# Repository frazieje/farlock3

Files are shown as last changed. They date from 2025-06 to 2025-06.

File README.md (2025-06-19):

Farlock3 is the 3rd generation of the FAR Door Lock. This version introduces several major changes over previous revisions.

This repository holds the KiCad schematic, PCB, BOM, and production files (gerber).

Features:

* New PCB design and layout
* nrf52840 SoC (MDBTQ50-U1MV2)
* Integrated h-bridge motor controller
* Integrated switch and LED electronics
* 64Mb external flash storage for Matter DFU
* USB micro B port for charging, shell access, etc
* ESD protection
* 3.3v voltage regulator
* Matter/ZephyrRTOS/OpenThread ready 

[farlock3 v02 schematic](farlock3.pdf)

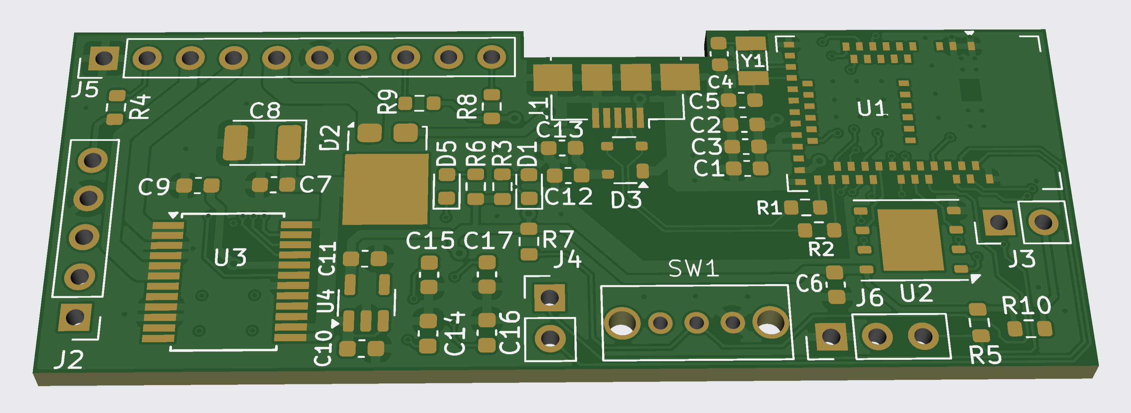
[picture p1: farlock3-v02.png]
farlock3 v02 PCB render


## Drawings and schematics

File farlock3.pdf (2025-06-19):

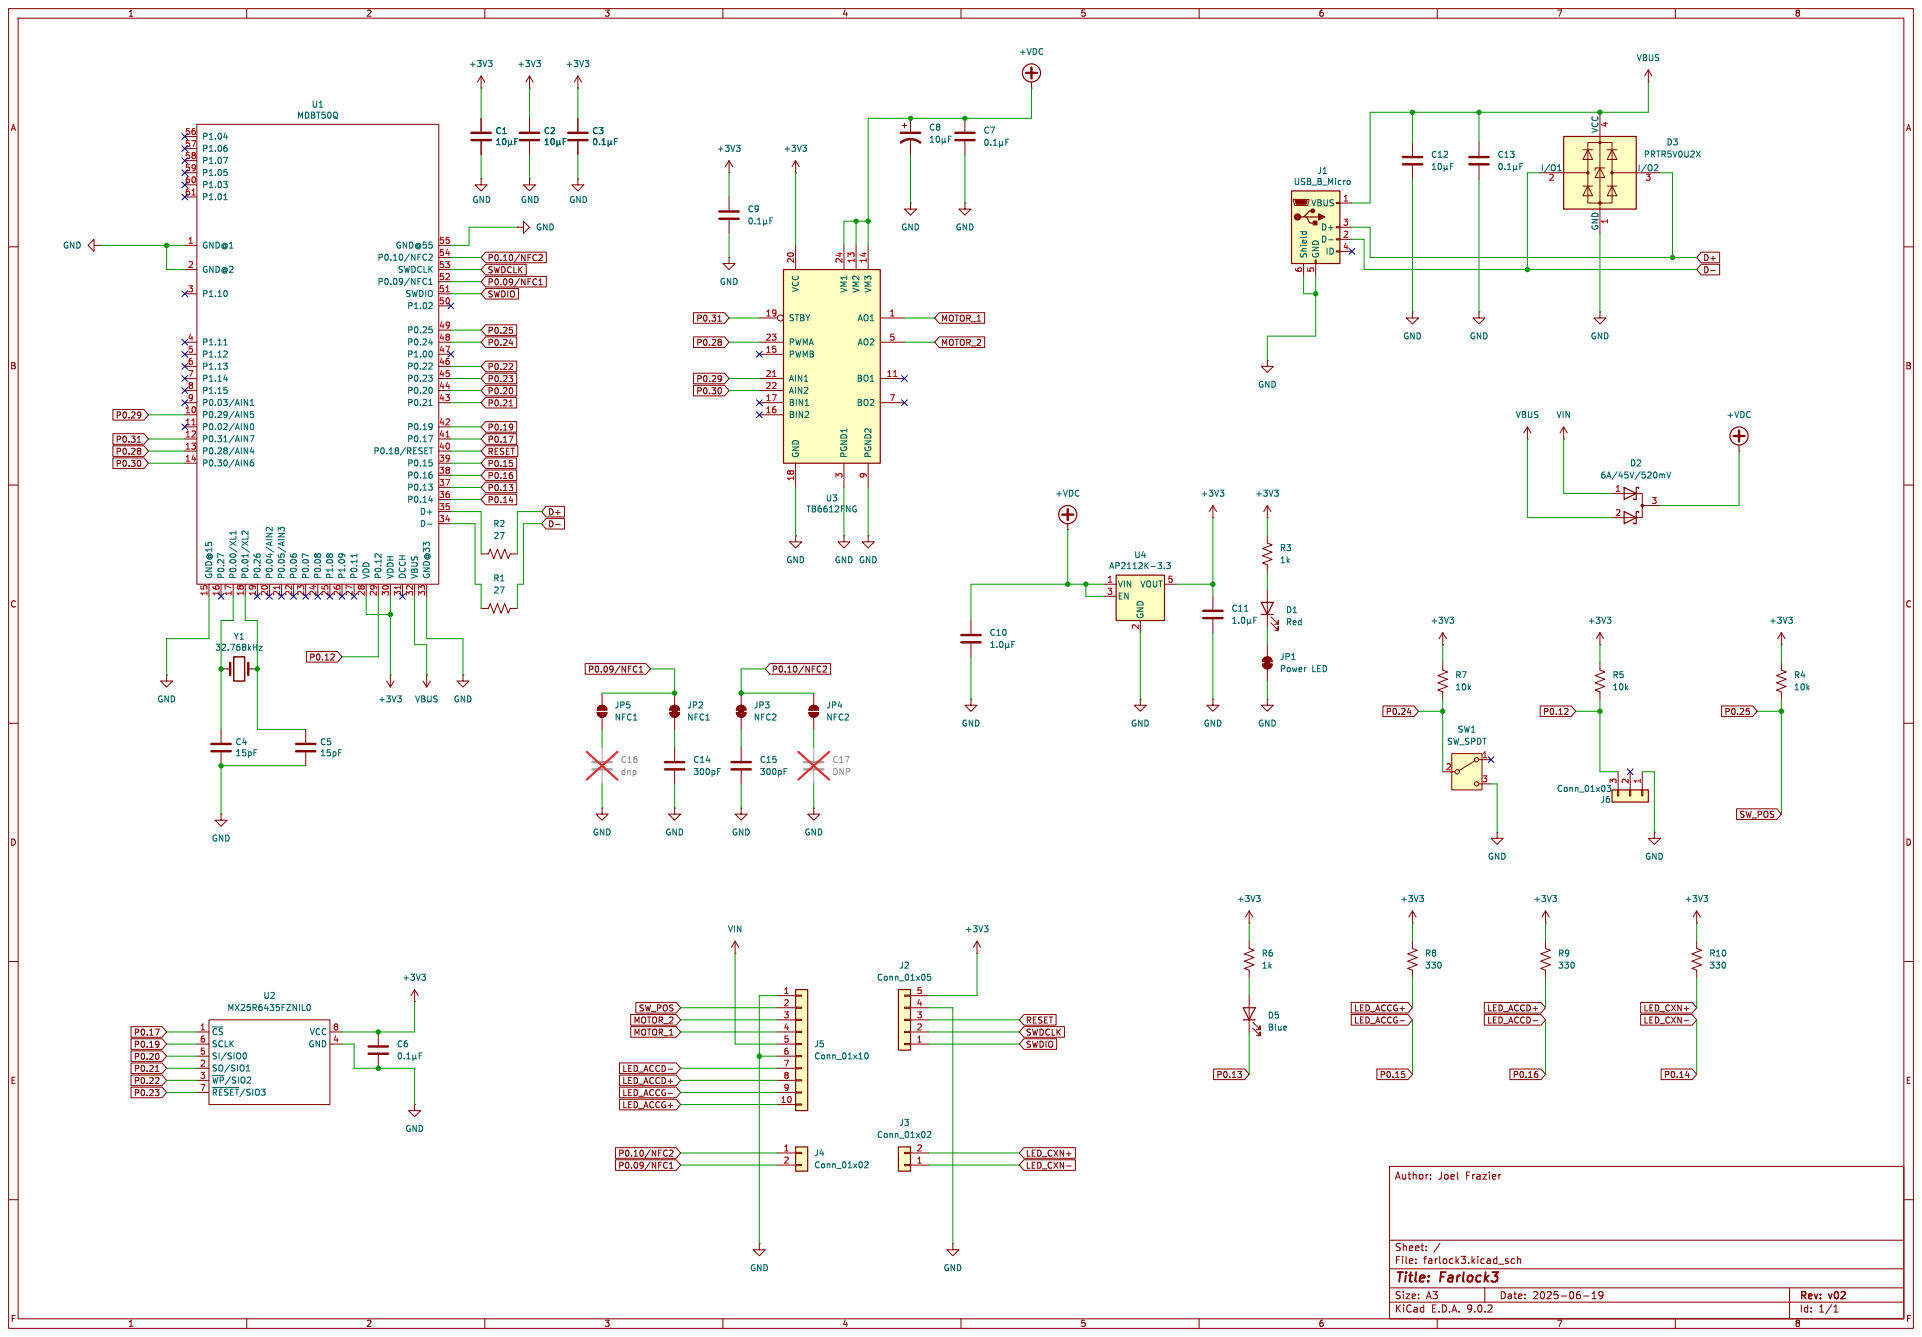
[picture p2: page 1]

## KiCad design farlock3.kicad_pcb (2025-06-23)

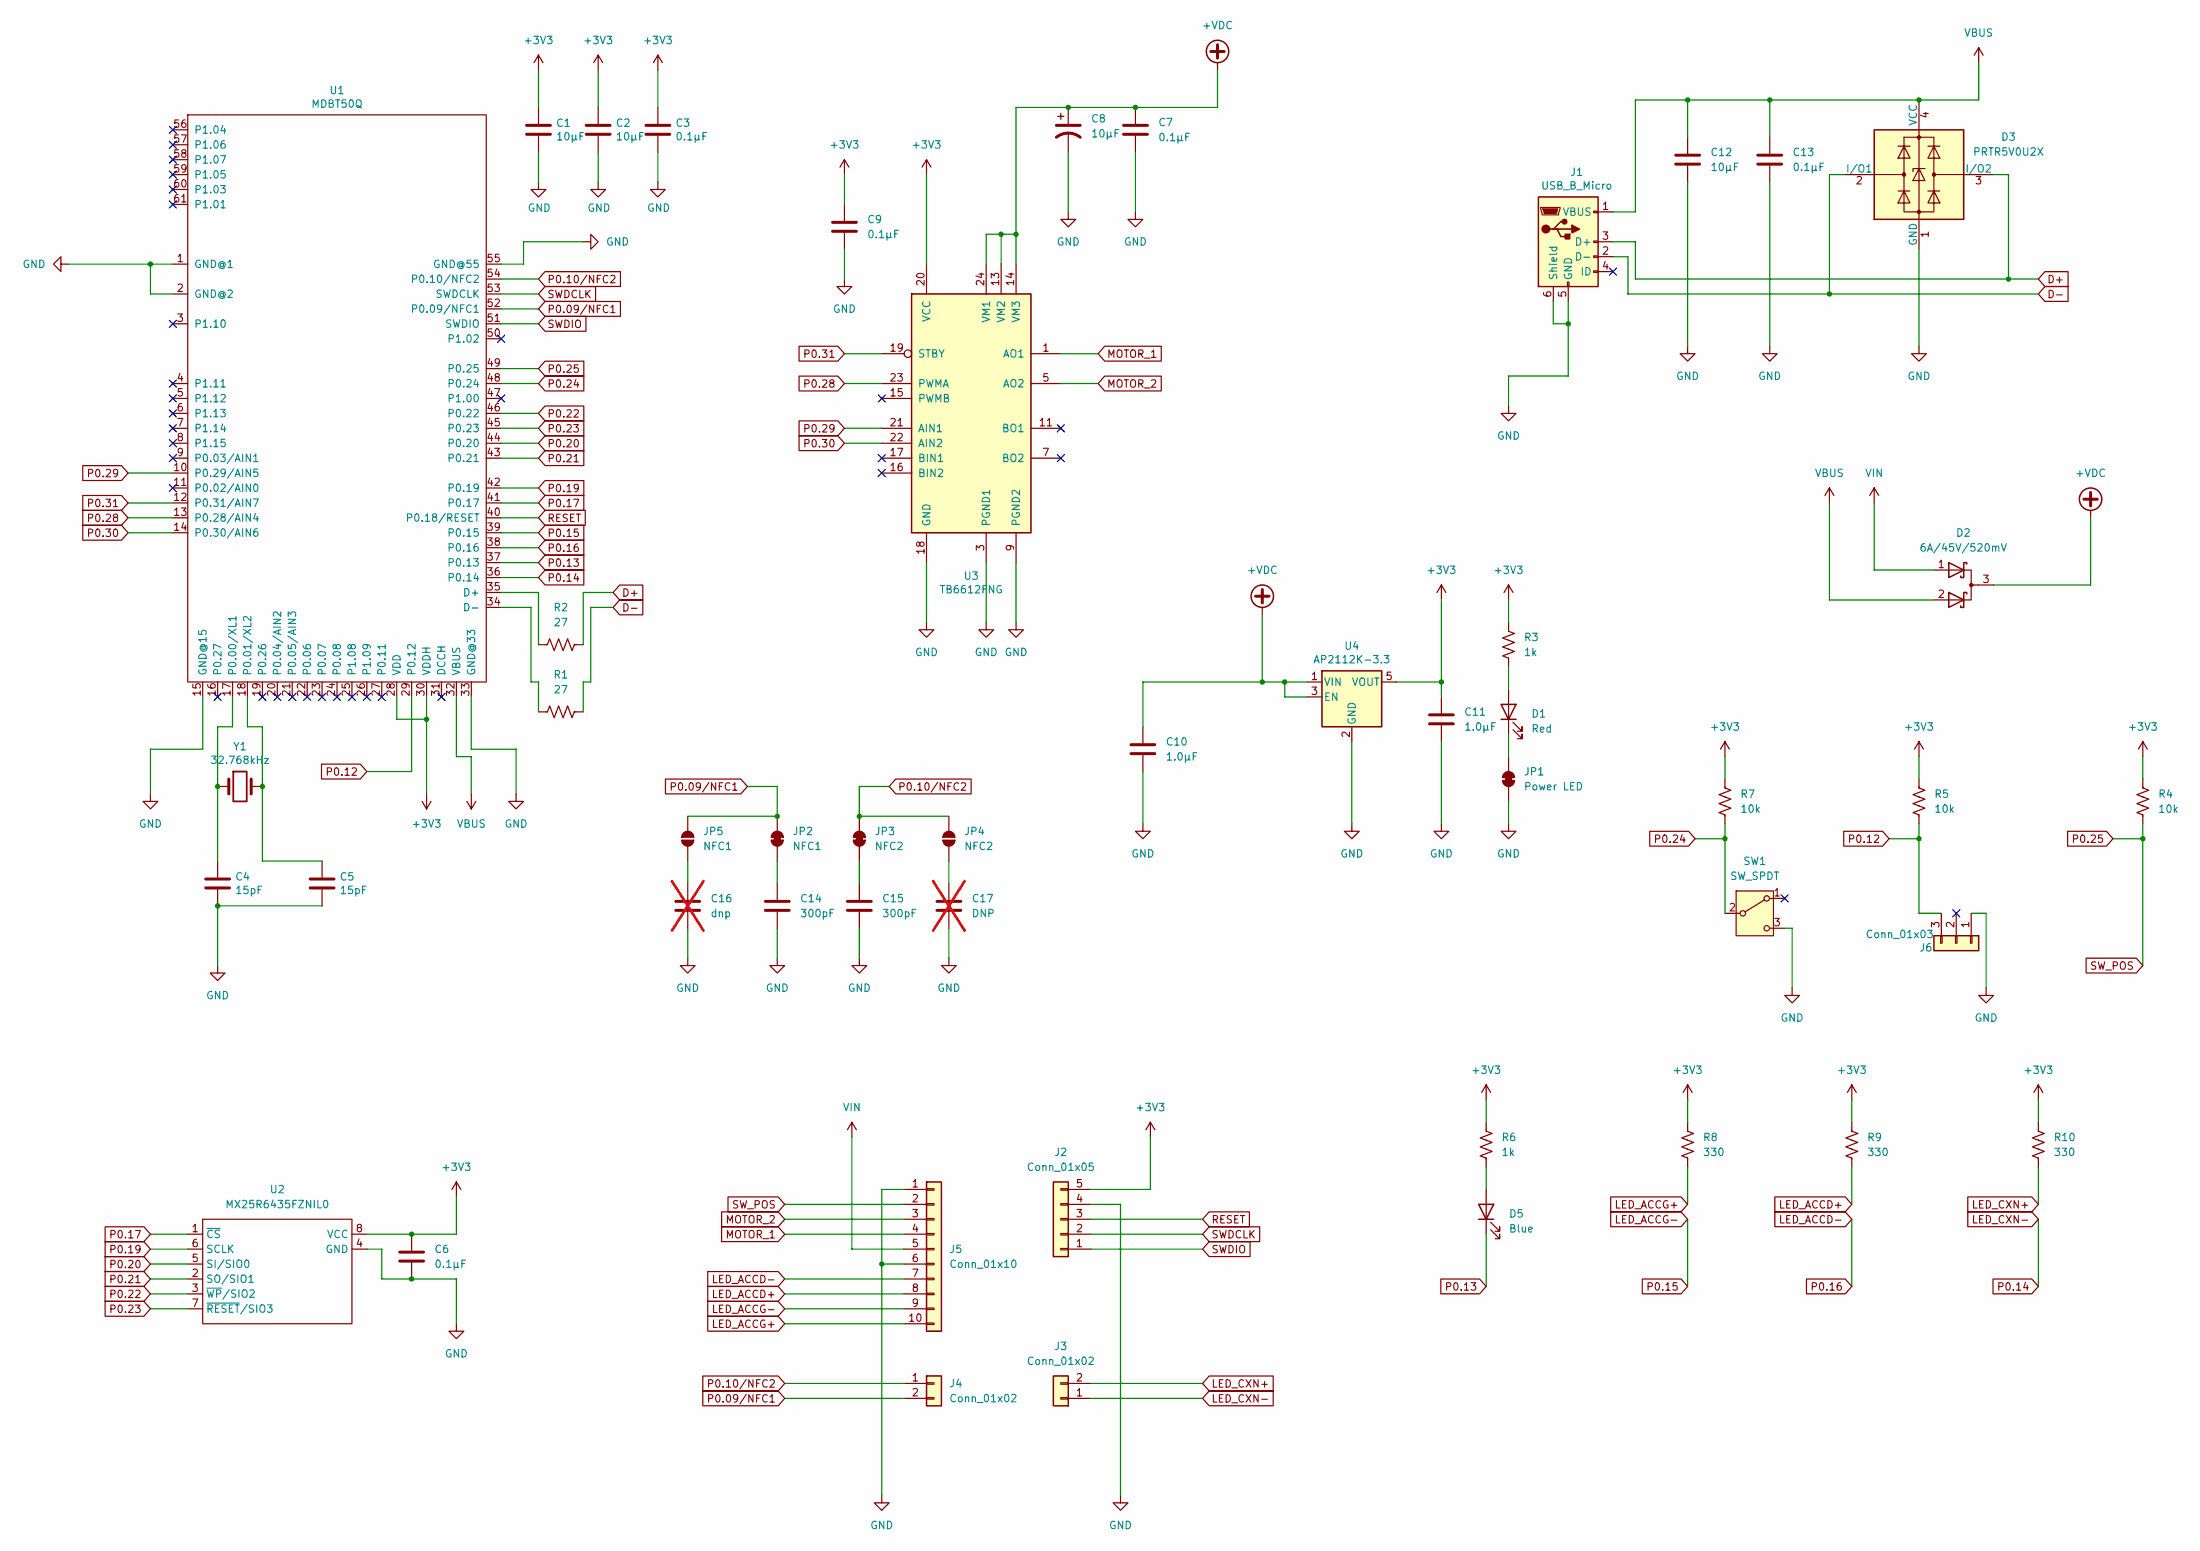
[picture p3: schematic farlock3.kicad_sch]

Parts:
C1, C2, C12: 10µF; C_0603_1608Metric; Manufacturer Part No CL10A106MP8NNNC
C3, C6, C7, C9, C13: 0.1µF; C_0603_1608Metric; Manufacturer Part No CL10B104KA8NNNC
C4, C5: 15pF; C_0603_1608Metric; Manufacturer Part No CL10C150JB8NNNC
C8: 10µF; CP_EIA-3528-21_Kemet-B; Manufacturer Part No 593D106X9020B2TE3
C10, C11: 1.0µF; C_0603_1608Metric; Manufacturer Part No CL10A105KO8NNNC
C14, C15: 300pF; C_0603_1608Metric; Manufacturer Part No C0603C301F5HACTU
C16: dnp; C_0603_1608Metric; not fitted
C17: DNP; C_0603_1608Metric; not fitted
D1: Red; LED_0603_1608Metric; Manufacturer Part No LTST-C190KRKT
D2: 6A/45V/520mV; TO-277A; Manufacturer Part No V10PL45-M3/86A
D3: PRTR5V0U2X; SOT-143; Manufacturer Part No PRTR5V0U2X
D5: Blue; LED_0603_1608Metric; Manufacturer Part No KB EELP41.12-P1R2-36-3X4X-5-R18
J1: USB_B_Micro; USB_Micro-B_Amphenol_10104110_Horizontal; Manufacturer Part No 10104110-0001LF
J2: Conn_01x05; PinHeader_1x05_P2.54mm_Vertical
J3, J4: Conn_01x02; PinHeader_1x02_P2.54mm_Vertical
J5: Conn_01x10; PinHeader_1x10_P2.54mm_Vertical
J6: Conn_01x03; PinHeader_1x03_P2.54mm_Vertical
JP1: Power LED; SolderJumper-2_P1.3mm_Bridged_RoundedPad1.0x1.5mm
JP2: NFC1; SolderJumper-2_P1.3mm_Bridged_RoundedPad1.0x1.5mm
JP3: NFC2; SolderJumper-2_P1.3mm_Bridged_RoundedPad1.0x1.5mm
JP4: NFC2; SolderJumper-2_P1.3mm_Open_RoundedPad1.0x1.5mm
JP5: NFC1; SolderJumper-2_P1.3mm_Open_RoundedPad1.0x1.5mm
R1, R2: 27; R_0603_1608Metric; Manufacturer Part No ERA-3AHD270V
R3, R6: 1k; R_0603_1608Metric; Manufacturer Part No ERA-3AEB102V
R4, R5, R7: 10k; R_0603_1608Metric; Manufacturer Part No ERJ-3GEYJ103V
R8, R9, R10: 330; R_0603_1608Metric; Manufacturer Part No ERA-3AEB331V
SW1: SW_SPDT; OS102011MA1QN1; Manufacturer Part No OS102011MA1QN1
U1: MDBT50Q; MDBT50Q-U1M; Manufacturer Part No MDBT50Q-U1MV2
U2: MX25R6435FZNIL0; WSON-8-1EP_6x5mm_P1.27mm_EP3.4x4mm; Manufacturer Part No MX25R6435FZNIL0
U3: TB6612FNG; SSOP-24_5.3x8.2mm_P0.65mm; Manufacturer Part No TB6612FNG,C,8,EL
U4: AP2112K-3.3; SOT-23-5; Manufacturer Part No AP2112K-3.3TRG1
Y1: 32.768kHz; Crystal_SMD_3215-2Pin_3.2x1.5mm; Manufacturer Part No CM7V-T1A-LOW-ESR-32.768KHZ-9PF-20-TA-QC

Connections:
+3V3: C1.1, C2.1, C3.1, C6.1, C9.1, C11.1, J2.5, R3.1, R4.2, R5.2, R6.1, R7.2, R8.1, R9.1, R10.1, U1.28 (VDD), U1.30 (VDDH), U2.8 (VCC), U3.20 (VCC), U4.5 (VOUT)
+VDC: C7.1, C8.1, C10.1, D2.3 (K), U3.13 (VM2), U3.14 (VM3), U3.24 (VM1), U4.1 (VIN), U4.3 (EN)
D+: D3.3 (I/O2), J1.3 (D+), R2.2
D-: D3.2 (I/O1), J1.2 (D-), R1.2
GND: C1.2, C2.2, C3.2, C4.2, C5.2, C6.2, C7.2, C8.2, C9.2, C10.2, C11.2, C12.2, C13.2, C14.2, C15.2, C16.2, C17.2, D3.1 (GND), J1.5 (GND), J1.6 (Shield), J2.4, J5.1, J5.6, J6.1, JP1.1 (A), SW1.3 (C), U1.1 (GND@1), U1.2 (GND@2), U1.15 (GND@15), U1.33 (GND@33), U1.55 (GND@55), U2.4 (GND), U3.3 (PGND1), U3.4 (PGND1), U3.9 (PGND2), U3.10 (PGND2), U3.18 (GND), U4.2 (GND)
LED_ACCD+: J5.8, R9.2
LED_ACCD-: J5.7, U1.38 (P0.16)
LED_ACCG+: J5.10, R8.2
LED_ACCG-: J5.9, U1.39 (P0.15)
LED_CXN+: J3.2, R10.2
LED_CXN-: J3.1, U1.36 (P0.14)
MOTOR_1: J5.4, U3.1 (AO1), U3.2 (AO1)
MOTOR_2: J5.3, U3.5 (AO2), U3.6 (AO2)
unnamed: D1.2 (A), R3.2
unnamed: D1.1 (K), JP1.2 (B)
unnamed: D5.2 (A), R6.2
unnamed: C14.1, JP2.1 (A)
unnamed: C15.1, JP3.1 (A)
unnamed: C17.1, JP4.1 (A)
unnamed: C16.1, JP5.1 (A)
unnamed: R2.1, U1.35 (D+)
unnamed: R1.1, U1.34 (D-)
unnamed: C4.1, U1.17 (P0.00/XL1), Y1.1
unnamed: C5.1, U1.18 (P0.01/XL2), Y1.2
P0.09/NFC1: J4.2, JP2.2 (B), JP5.2 (B), U1.52 (P0.09/NFC1)
P0.10/NFC2: J4.1, JP3.2 (B), JP4.2 (B), U1.54 (P0.10/NFC2)
P0.12: J6.3, R5.1, U1.29 (P0.12)
P0.13: D5.1 (K), U1.37 (P0.13)
P0.17: U1.41 (P0.17), U2.1 (~CS)
P0.19: U1.42 (P0.19), U2.6 (SCLK)
P0.20: U1.44 (P0.20), U2.5 (SI/SIO0)
P0.21: U1.43 (P0.21), U2.2 (SO/SIO1)
P0.22: U1.46 (P0.22), U2.3 (~WP/SIO2)
P0.23: U1.45 (P0.23), U2.7 (~RESET/SIO3)
P0.24: R7.1, SW1.2 (B), U1.48 (P0.24)
P0.25: J5.2, R4.1, U1.49 (P0.25)
P0.28: U1.13 (P0.28/AIN4), U3.23 (PWMA)
P0.29: U1.10 (P0.29/AIN5), U3.21 (AIN1)
P0.30: U1.14 (P0.30/AIN6), U3.22 (AIN2)
P0.31: U1.12 (P0.31/AIN7), U3.19 (STBY)
RESET: J2.3, U1.40 (P0.18/RESET)
SWDCLK: J2.2, U1.53 (SWDCLK)
SWDIO: J2.1, U1.51 (SWDIO)
VBUS: C12.1, C13.1, D2.2 (A), D3.4 (VCC), J1.1 (VBUS), U1.32 (VBUS)
VIN: D2.1 (A), J5.5

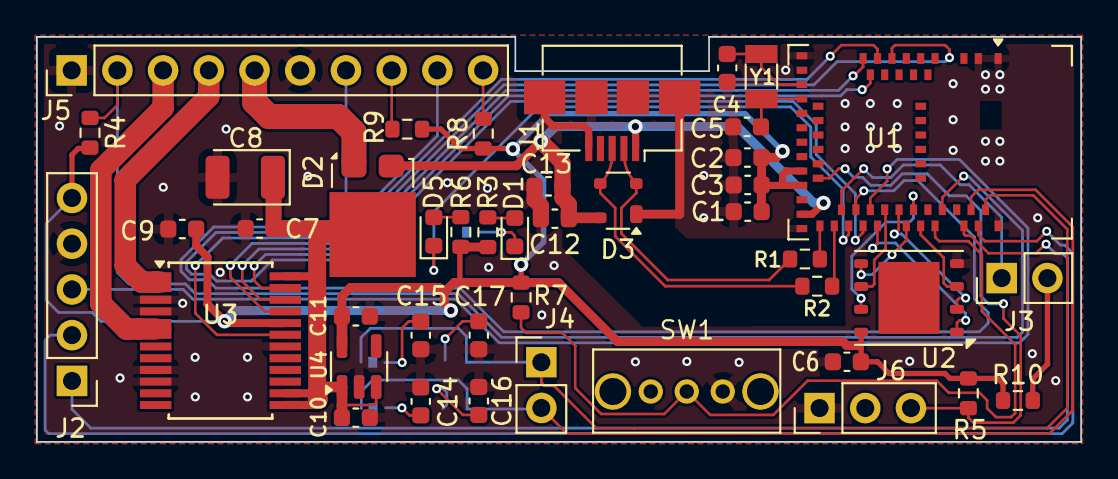
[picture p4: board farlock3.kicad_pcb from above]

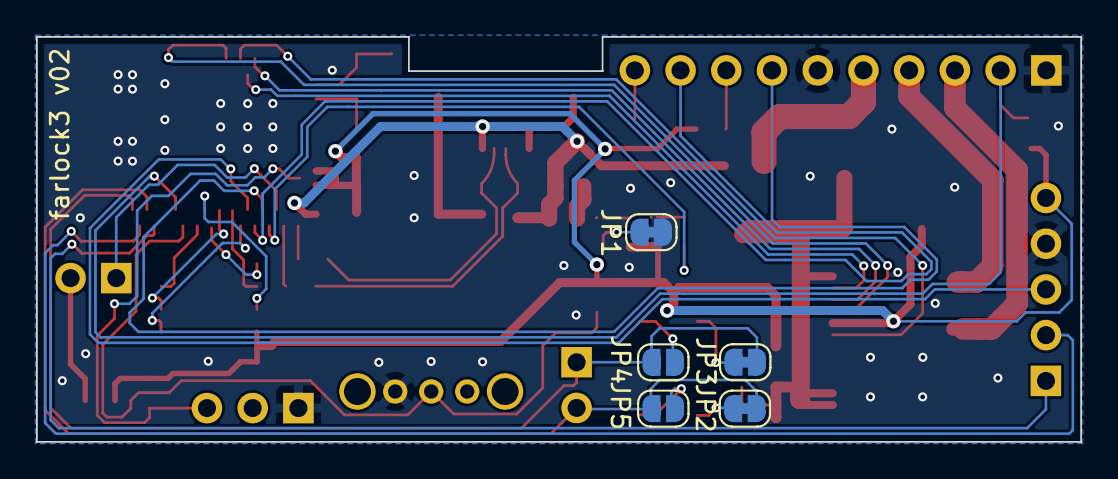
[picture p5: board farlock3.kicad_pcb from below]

Board: 2 copper layers, 58.0 x 22.5 mm, 48 parts (5 on the bottom side), 45 nets.

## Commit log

2025-05-29 use new kicad formats, add MDBT50Q lib
    [farlock3.kicad_sch, farlock3.sch]
2025-06-14 farlock3 v01 layout, production files
    [farlock3-B_Cu.gbl, farlock3-B_Mask.gbs, farlock3-B_Paste.gbp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]
2025-06-19 v02 redesign
    [farlock3-B_Cu.gbl, farlock3-B_Mask.gbs, farlock3-B_Paste.gbp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]
2025-06-19 add schematic PDF and board render
2025-06-23 increase minimum track width, spacing, and annular ring size - support more board fabrication houses
    [farlock3.kicad_pcb]
